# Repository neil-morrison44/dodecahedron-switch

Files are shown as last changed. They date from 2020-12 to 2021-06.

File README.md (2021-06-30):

# dodecahedron-switch
Sort of a (probably more expensive) (less good) DIY version of [the nanoleaf remote](https://www.youtube.com/watch?v=FFnLSsW_xBE)

| Setting HomeKit Scenes | Charging |
| --- | --- |
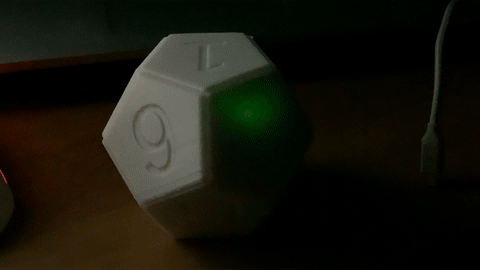
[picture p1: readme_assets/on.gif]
turning on
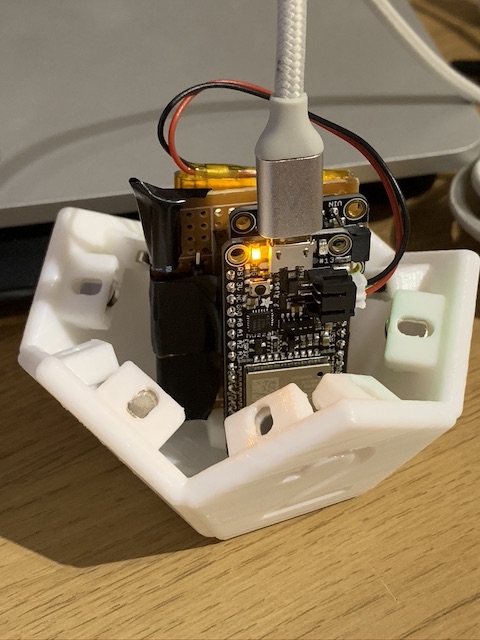
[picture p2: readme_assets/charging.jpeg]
Charging
| turning off |  |
## BOM

| Part | Link |
|--|--|
| ~~Adafruit HUZZAH32~~ (MK 1) | https://thepihut.com/products/adafruit-huzzah32-esp32-feather-board-ada3405?variant=12364065701950 |
|TinyPICO (MK 1) | https://thepihut.com/products/tinypico-esp32-development-board|
|Fast Vibration Sensor Switch| https://thepihut.com/products/fast-vibration-sensor-switch-easy-to-trigger?variant=27739606289 |
| Adafruit LSM6DS33 + LIS3MDL - 9 DoF IMU with Accel / Gyro / Mag | https://thepihut.com/products/adafruit-lsm6ds33-lis3mdl-9-dof-imu-with-accel-gyro-mag?variant=31486702354494 |
| EEMB 3.7V 1100mAh 603449 Lipo Battery | https://www.amazon.co.uk/gp/product/B08FD39Y5R |
|Yizhet 50pcs N38 Neodymium Strong Magnets | https://www.amazon.co.uk/gp/product/B074C79DJS |
| SUNLU PLA plus white | https://www.amazon.co.uk/gp/product/B07R8X76GW |
| perfboard, wires, connectors etc ||

## Construction

- The magnets fit into the slots within the upper & lower halves, 2 pairs of magnets should be reversed so the two halves have a prefered way of clasping together
- Once the circuit's on the perfboard chop off some of the excess board & use the [circuit_connector](./models/circuit_connector.stl) (and probably some hot glue) to attach it with the top of the ESP32 facing the number 2.

## MK2 Improvements

- Switched from the Adafruit HUZZAH32 (which uses 7000µA in deep sleep) to the TinyPICO (which uses ~29µA in deep sleep) which _should_ have a noticable effect on the battery life
- Started powering the IMU component from a GPIO pin after seeing that it used about 1.43mA max (well under the 12mA that it's safe to pull from a GPIO pin)
- Didn't 3D print a new case / use a new proto-board so there's a bunch of extra electrical tape, hot glue and solder

# Possible improvements
 - Expose as real homekit device rather than use Homebridge-mqtt, there's an ESP32 homebridge library but it looked complicated & didn't appear to work in ardiuno mode
 - Internal LEDs, I bought some planning to put them in but I couldn't be bothered with the additional power draw & complexity
 - ~~Use a transistor to power on the gyro only when it's needed - didn't realise until I'd wired it up that the gryo / accelerometer chip has an always on LED + all the processing it's presumably doing. Could have it powered off during sleep then power on wake.~~
 - Wait for movement to stop before sending messages, I thought this would be a bigger deal than it seems to be, there's a CSV of readings taken while moving which could be used to train a tensorflow model to check if it's in motion.
 - Use actual math instead of a tensorflow model to tell which side is up. Less fun, but probably quicker.

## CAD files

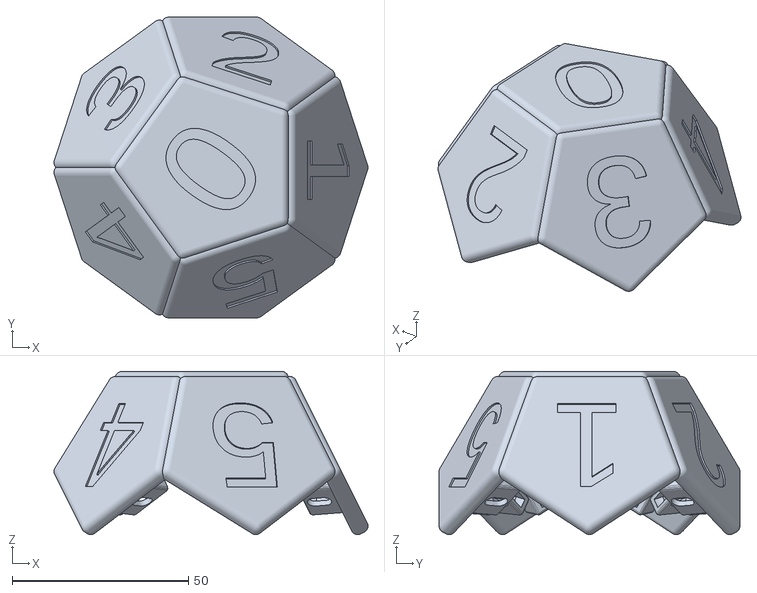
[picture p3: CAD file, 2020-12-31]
models/lower_half.stl
89.1 x 85.4 x 46.3

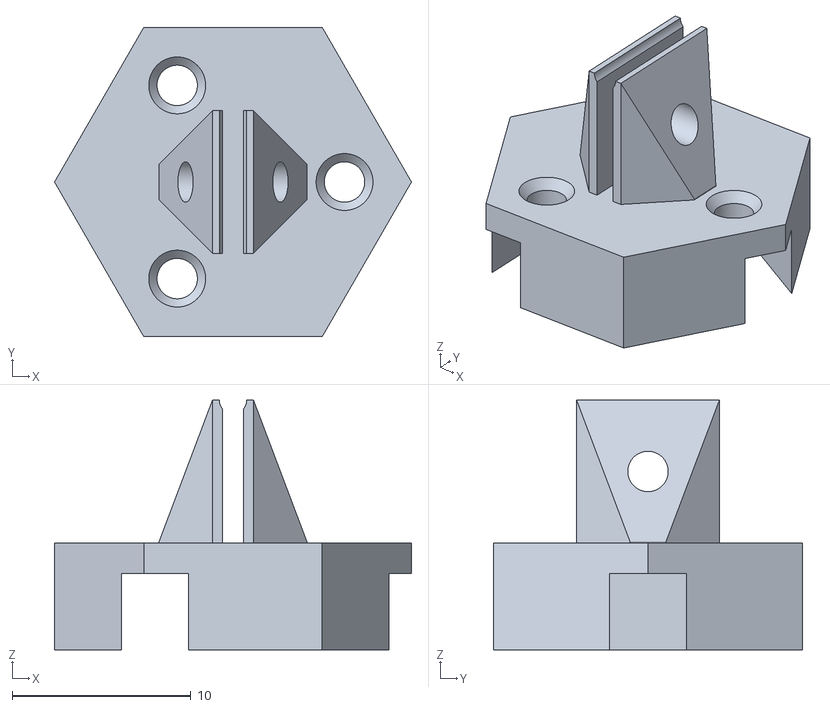
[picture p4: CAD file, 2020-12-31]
models/circuit_connector.stl
20.0 x 17.3 x 14.0

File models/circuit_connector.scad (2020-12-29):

use <./half.scad>
$fn = 360;

$screwRadius = 2.26 / 2;
$tileRadius = 25;

$height = 6;

$boardThickness = 1.15;

$clipHeight = 8;
$clipWidth = 8;

module connector() {
    difference() {
        cylinder($fn = 6, r = 10, h = $height);

        for (i = [0:360 / 3:360]) {
            rotate([ 0, 0, i ]) translate([ $tileRadius / 4, 0, -0.1 ]) {
                cylinder($height + 1, $screwRadius, $screwRadius);
                translate([ 0, 0, $height - 0.5 ])
                    cylinder(0.65, $screwRadius, $screwRadius + 0.5);
            }
        }
    }
}

module boardClip() {
    translate([ 0, 0, ($clipHeight / 2) + $height ]) {
        difference() {
            hull() {
                cube([ $boardThickness * 2, $clipWidth, $clipHeight ], true);
                for (i = [ -3, 3 ]) {
                    translate([ i, 0, -($clipHeight / 2) ]) {
                        cube([ $boardThickness * 2, 2, 0.1 ], true);
                    }
                }
            }
            cube([ $boardThickness, $clipWidth + 2, $clipHeight + 1 ], true);
            // lips
            translate([0,($clipWidth + 1) / 2,$clipHeight / 2])
            rotate([90, 0, 0])
            cylinder($clipWidth + 1, $boardThickness /1.5, $boardThickness / 1.5);
            
            //screwHole
            
            translate([-5, 0, 0])
            rotate([0, 90, 0])
            cylinder(10, $screwRadius, $screwRadius);
        }
    }
}

difference() {
    connector();
    scale([ 1, 1, 1.1 ]) translate([ 0, 0, -0.1 ]) screwConnector();
}

boardClip();

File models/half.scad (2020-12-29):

$fs = 0.5;
$fa = 0.1;

$tileRadius = 25;
$magnetRadius = 4.1;
$magnetHeight = 2.8;

$tileChafer = 2;

$tileSideLength = (($tileRadius + ($tileChafer)) * sin(72 / 2)) * 2;

$containingSphereRadius = ($tileSideLength / 4) * (sqrt(15) + sqrt(3));

$insideSphereRadius =
    ($tileSideLength / 2) * sqrt((5 / 2) + ((11 / 10) * sqrt(5)));

$screwRadius = 2.25 / 2;

$startNumber = 0;

$dodecNumber = 116.565;

module magnetConnector() {
    translate([ 0, 0, 0 ]) difference() {
        minkowski() {
            cube([ $magnetRadius, $tileRadius / 2, 10 ], true);
            sphere(r = 1);
        }
        rotate([ 0, -90, 0 ]) {
            translate([ 2.75, 0, 0 ]) {
                cylinder($magnetHeight, $magnetRadius, $magnetRadius, true);
                hull() {
                    translate([ -3, 0, 0 ])
                        cylinder($magnetHeight * 3, $magnetRadius / 2,
                                 $magnetRadius / 2, true);
                    cylinder($magnetHeight * 3, $magnetRadius / 2,
                             $magnetRadius / 2, true);
                }
                translate([ $magnetRadius * 0.95, 0, 0 ]) scale([ 1, 1, 1 ])
                    cylinder($magnetHeight, $magnetRadius + 1,
                             $magnetRadius + 1, true);
            }
        }
    }
}

module screwConnector() {
    difference() {
        cylinder($fn = 3, r = $tileRadius / 2, h = 4);

        for (i = [0:360 / 3:360]) {
            rotate([ 0, 0, i ]) translate([ $tileRadius / 4, 0, 0.1 ])
                cylinder(5, $screwRadius, $screwRadius);
        }
    }
}

module pentagon(number = "1", hasMagnets = false, hasScrews = false,
                numberAngle = -90, depth = 1.5) {
    rotate([ 180, 0, 0 ]) {
        difference() {
            union() {
                minkowski() {
                    cylinder($fn = 5, r = $tileRadius, h = 1);
                    sphere(r = $tileChafer);
                }

                if (hasMagnets) {
                    for (angle = [ -(72 / 2), (72 / 2) ]) {
                        rotate([ 0, 0, angle ])
                            translate([ $tileRadius * 0.585, 0, 5 ])
                                rotate([ 0, -($dodecNumber - 90), 0 ])
                                    magnetConnector();
                    }
                }

                if (hasScrews) {
                    translate([ 0, 0, 3 ]) screwConnector();
                }
            }
            scale([ 1, -1, 1 ]) translate([ 0, 0, -(5 + depth) ])
                linear_extrude(height = 5) {
                rotate([ 0, 0, numberAngle ])
                    text(number, size = $tileRadius * 1.1, halign = "center",
                         valign = "center");
            }
        }
    }
}

module bottom() {
    rotate([ 0, 0, -(72 / 2) ]) translate([ 0, 0, $insideSphereRadius ])
        pentagon(number = str($startNumber), hasScrews = true);

    for (i = [0:72:360 - 72]) {
        $number = str((i / 72) + ($startNumber) + 1);
        rotate([ 0, (180 - $dodecNumber), i ])
            translate([ 0, 0, $insideSphereRadius ])
                pentagon(number = $number, hasMagnets = true);
    }
}
moduletop() {
    for (i = [0:72:360 - 72]) {
        $number = str((i / 72) + ($startNumber + 5) + 1);
        rotate([ 0, ($dodecNumber), (-72 / 2) + i ])
            translate([ 0, 0, $insideSphereRadius ]) rotate([ 0, 0, 180 ])
                pentagon(number = $number, hasMagnets = true, numberAngle = 90);
    }
    rotate([ 180, 0, 0 ]) translate([ 0, 0, $insideSphereRadius ]) pentagon(
        number = str($startNumber + 11), hasScrews = true, depth = 0.5);
}
difference() {
    top();
    bottom();
}

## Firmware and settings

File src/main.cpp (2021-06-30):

// Basic demo for accelerometer/gyro readings from Adafruit LSM6DS33
#include <WiFi.h>
#include <Adafruit_LSM6DS33.h>
#include <PubSubClient.h>
#include <secrets.h>
#include <predict_value.h>
#include <TinyPICO.h>

#define VIBRATION_SWITCH_PIN 25
#define IMU_POWER_PIN 27
#define WIFI_TIMEOUT_MS 30000

#define TIME_TO_SLEEP 60 * 60 * 24
#define uS_TO_S_FACTOR 1000000LL

WiFiClient espClient;
PubSubClient client(espClient);
unsigned long lastMsg = 0;
#define MSG_BUFFER_SIZE (128)
char msg[MSG_BUFFER_SIZE];
int value = 0;

TinyPICO tp = TinyPICO();

Adafruit_LSM6DS33 lsm6ds33;

RTC_DATA_ATTR int bootCount = 0;
// RTC_DATA_ATTR int lastPrediction = -1;

bool wifiConnected = false;
bool messagesSent = false;

void connectToMQTT()
{
  Serial.println("connecting to MQTT");
  client.setServer(MQTT_HOST, MQTT_PORT);
  client.connect("dodec");
}

void WiFiEvent(WiFiEvent_t event)
{
  Serial.printf("[WiFi-event] event: %d\n", event);
  switch (event)
  {
  case SYSTEM_EVENT_STA_START:
    WiFi.setHostname(HOSTNAME);
    break;
  case SYSTEM_EVENT_STA_GOT_IP:
    Serial.println("Connected to Wi-Fi.");

    Serial.print("ESP32 hostname: ");
    Serial.println(String(WiFi.getHostname()));
    Serial.print("ESP32 MAC: ");
    Serial.println(WiFi.macAddress());
    Serial.print("ESP32 IP: ");
    Serial.println(WiFi.localIP());
    Serial.print("Wi-Fi signal level: ");
    Serial.println(WiFi.RSSI());

    wifiConnected = true;
    connectToMQTT();
    break;
  case SYSTEM_EVENT_STA_DISCONNECTED:
    wifiConnected = false;
    Serial.println("Disconnected from Wi-Fi.");
    break;
  }
}

void setupWakeEvents()
{
  esp_sleep_enable_ext0_wakeup(GPIO_NUM_25, HIGH);
  esp_sleep_enable_timer_wakeup(TIME_TO_SLEEP * uS_TO_S_FACTOR);
}

void connectToWifi()
{
  Serial.println("Connecting to Wi-Fi...");
  WiFi.onEvent(WiFiEvent);
  WiFi.begin(SSID, PASSWORD);
}

void registerDevice()
{
  Serial.println("Registering device...");

  // sprintf(msg, "{\"name\": \"dodecahedron\"}");
  // client.publish("homebridge/to/remove", msg);

  sprintf(msg, "{\"name\": \"dodecahedron\",\"service_name\": \"face 0\", \"service\": \"Switch\" }");
  client.publish("homebridge/to/add", msg);

  for (int i = 1; i < 12; i++)
  {
    sprintf(msg, "{\"name\": \"dodecahedron\",  \"service_name\": \"face %d\", \"service\": \"Switch\" }", i);
    client.publish("homebridge/to/add/service", msg);
  }

  sprintf(msg, "{\"name\": \"dodecahedron\",  \"service_name\": \"battery\", \"service\": \"BatteryService\" }");
  client.publish("homebridge/to/add/service", msg);

  // delay(100);
}

void sendMessage()
{
  Serial.println("Sending message");

  sensors_event_t accel;
  sensors_event_t gyro;
  sensors_event_t temp;
  lsm6ds33.getEvent(&accel, &gyro, &temp);

  int prediction = predict(accel.acceleration.x, accel.acceleration.y, accel.acceleration.z, gyro.gyro.x, gyro.gyro.y, gyro.gyro.z);
  // if (prediction == lastPrediction)
  // {
  //   Serial.println("No change in prediction");
  //   return;
  // }
  for (int i = 0; i < 12; i++)
  {
    sprintf(msg, "{\"name\": \"dodecahedron\",  \"service_name\": \"face %d\", \"characteristic\": \"On\", \"value\": %d }", i, (i == prediction));
    client.publish("homebridge/to/set", msg);
  }

  // lastPrediction = prediction;
}

void sendBatteryMessage()
{
  Serial.println("Sending battery message");
  int batteryPercentage = map(tp.GetBatteryVoltage() * 1000, 3200, 4200, 0, 100);

  // sprintf(msg, "Battery: %d%%", batteryPercentage);
  // client.publish("test/battery", msg);

  // topic: homebridge/to/set
  // payload: {"name": "dodecahedron", "service_name": "battery", "characteristic": "BatteryLevel", "value": true}

  sprintf(msg, "{\"name\": \"dodecahedron\",  \"service_name\": \"battery\", \"characteristic\": \"BatteryLevel\", \"value\": %d }", batteryPercentage);
  client.publish("homebridge/to/set", msg);

  sprintf(msg, "{\"name\": \"dodecahedron\",  \"service_name\": \"battery\", \"characteristic\": \"StatusLowBattery\", \"value\": %d }", batteryPercentage < 20);
  client.publish("homebridge/to/set", msg);
}

void disconnectEverything()
{
  Serial.println("Disconnecting Everything...");
  digitalWrite(IMU_POWER_PIN, LOW);
  tp.DotStar_SetPower(false);
  client.disconnect();
  delay(20);
  WiFi.disconnect();
  delay(80);
}

void gotoSleep()
{
  client.loop();
  Serial.println("Going to sleep...");
  disconnectEverything();
  esp_deep_sleep_start();
}

void onWake()
{
  esp_sleep_wakeup_cause_t wakeup_reason = esp_sleep_get_wakeup_cause();

  switch (wakeup_reason)
  {
  case ESP_SLEEP_WAKEUP_EXT0:
    Serial.println("Wakeup caused by external signal using RTC_IO");
    sendMessage();
    sendBatteryMessage();
    gotoSleep();
    break;
  case ESP_SLEEP_WAKEUP_TIMER:
    Serial.println("Wakeup caused by timer");
    sendBatteryMessage();
    gotoSleep();
    break;
  default:
    Serial.printf("Battery Voltage: %f\n", tp.GetBatteryVoltage());
    Serial.printf("Wakeup was not caused by deep sleep: %d\n", wakeup_reason);
    registerDevice();
    delay(1000);
    gotoSleep();
    break;
  }
}

void setup(void)
{

  // pinMode(VIBRATION_SWITCH_PIN, INPUT);

  pinMode(IMU_POWER_PIN, OUTPUT);
  digitalWrite(IMU_POWER_PIN, HIGH);

  setupWakeEvents();

  Serial.begin(9600);
  delay(100);
  while (!Serial)
    delay(10); // will pause Zero, Leonardo, etc until serial console opens

  connectToWifi();

  Serial.println("Adafruit LSM6DS33 test!");

  if (!lsm6ds33.begin_I2C())
  {
    Serial.println("Failed to find LSM6DS33 chip");
    gotoSleep();
  }

  Serial.println("LSM6DS33 Found!");

  lsm6ds33.configInt1(false, false, true); // accelerometer DRDY on INT1
  lsm6ds33.configInt2(false, true, false); // gyro DRDY on INT2

  setupModel();

  ++bootCount;
  Serial.println("Boot number: " + String(bootCount));
}

void loop()
{
  if ((millis() > WIFI_TIMEOUT_MS) && !client.connected())
  {
    Serial.println("WiFI connection timedout");
    gotoSleep();
    return;
  }

  client.loop();

  if (wifiConnected && client.connected())
  {
    onWake();
  }
}

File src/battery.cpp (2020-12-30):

#include <Arduino.h>

#define VBAT_PIN A13
#define VBAT_SMOOTHING_COUNT 10
int vbatReadings[VBAT_SMOOTHING_COUNT];

int getBatteryPercentage()
{

  for (int i = 0; i < VBAT_SMOOTHING_COUNT; i++)
  {
    vbatReadings[i] = analogRead(VBAT_PIN);
    delay(10);
  }

  float sum = 0;
  for (int i = 0; i < VBAT_SMOOTHING_COUNT; i++)
  {
    sum += vbatReadings[i];
  }

  float smoothedVBAT = (sum / VBAT_SMOOTHING_COUNT);

  smoothedVBAT *= 2;     // we divided by 2, so multiply back
  smoothedVBAT *= 3.318; // 3.3v reference voltage
  smoothedVBAT /= 4095;  // convert to voltage

  // voltmeter adjustments
  // linear fit {3.51, 3.57} {3.52, 3.59} {3.57,3.63}{3.63, 3.70}{3.70, 3.76}{3.81,3.87}{3.885,3.94}{4.045,4.1}{4.15,4.20}
  // 0.977459 x + 0.144705

  smoothedVBAT = (0.977459 * smoothedVBAT) + 0.144705;

  Serial.print("smoothed ");
  Serial.print(smoothedVBAT);
  Serial.print("v");
  Serial.println();

  return map(smoothedVBAT * 1000, 3200, 4200, 0, 100);
}

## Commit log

2020-12-29 first commit, models and src files
    [circut_connector.scad, half.scad]
2020-12-30 use some machine learning to do the thing with angles that would be easy for anyone actually good at maths
    [moving.csv, position_0.csv, position_1.csv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]
2020-12-31 Add readmne with gifs & stl models
    [circuit_connector.scad, circuit_connector.stl, circut_connector.scad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]
2020-12-31 remove some dead space around the circuit diagram
2021-06-30 Switch to tinyPICO
